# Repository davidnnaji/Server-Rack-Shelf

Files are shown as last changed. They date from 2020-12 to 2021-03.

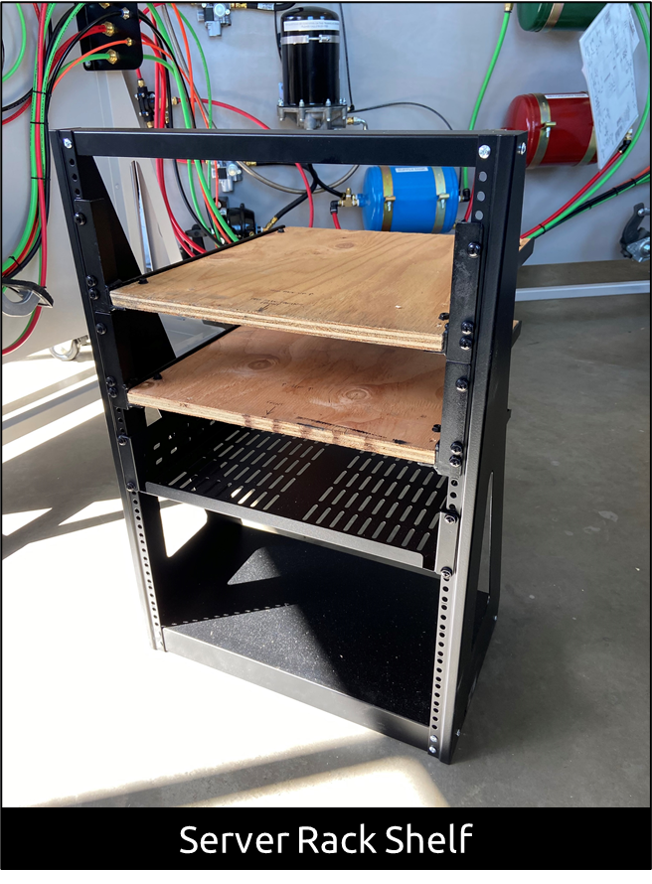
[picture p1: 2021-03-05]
serverrackshelf.png

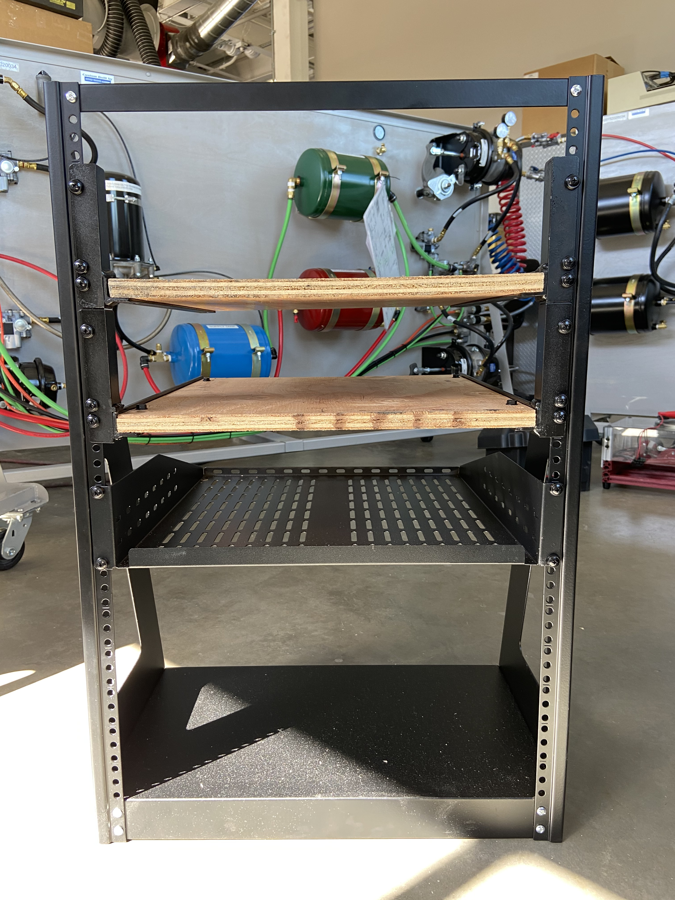
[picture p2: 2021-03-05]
Server Rack Shelf/Photos/IMG_8255.jpg

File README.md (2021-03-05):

# Server Rack Shelf
A wooden shelf for mounting on this [server rack](https://www.startech.com/en-us/server-management/2postrack16). Designed in Solidworks 2020. Project summary included in /docs.

# General Purpose Display Board
A general purpose display board for lab experiments. Ultimately, this did not suit my needs.

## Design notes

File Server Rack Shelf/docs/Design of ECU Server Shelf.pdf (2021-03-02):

# Design of ECU Server Shelf

### David Nnaji

# Problem Definition

## An engineering research group at CSU is developing a remote vehicle network test platform. Continuous operation of electronic control units (ECUs), computers, servers, and other electrical hardware is expected. An organized means of mounting ECU equipment in standard 19-inch racks (server racks) is

desired.

CUMMI
NS ECU

# Needs Analysis

Primary Function:
Support a vehicle ECU and its equipment on standard 19” racks Secondary Function(s):
None
Timeline:
January 1

st – January 30th 2021
Where:
Powerhouse Energy Institute Engine Control Room Who:
SystemsCyber Research Group

# Requirements

System Operational Requirements (SR)
- SR1 – System shall be securable to a standard 16U* 19” two-post server rack.
- SR2 – System height shall not exceed 3U.
- SR3 – System weight shall not exceed 52.5 lb. (15% of rack weight capacity).
- SR4 – At minimum, the system shall support an ECU, 12V power adapter, and an SSS2 unit.

*1U = 1.75 in.
Key Figures of Merit (FOMs):
Material Cost (Mc) – Dollars ($)
Manufacturing Time (Mt) – Hours
Composite Failure Rate (l) – Likelihood a shelf is not made according to design Total Design Cost (TC) – Per Shelf

# Design Alternatives

Alternative 1:
Acrylic-ABS Shelf and Display
Description: A desire for the shelf to doubly function as a project display board was considered but not included in the requirements. Alternative 1 attempts to satisfy this desire and the requirements by using laser cut 1/8” acrylic sheets, velcro, 3D-printed components, and available lab material.
Equipment Used:
Laser Cutter, 3D Printer, Power Drill

Alternative 2:
Wood-Steel Shelf
Description: Alternative 2 attempts to use welded 1/8 in. angle iron, screws, plywood, and available lab materials to satisfy the requirements.
Equipment Used:
Mill, Welding Station, Metal Grinder, Horizontal Band Saw, Wood Saw, Power Drill

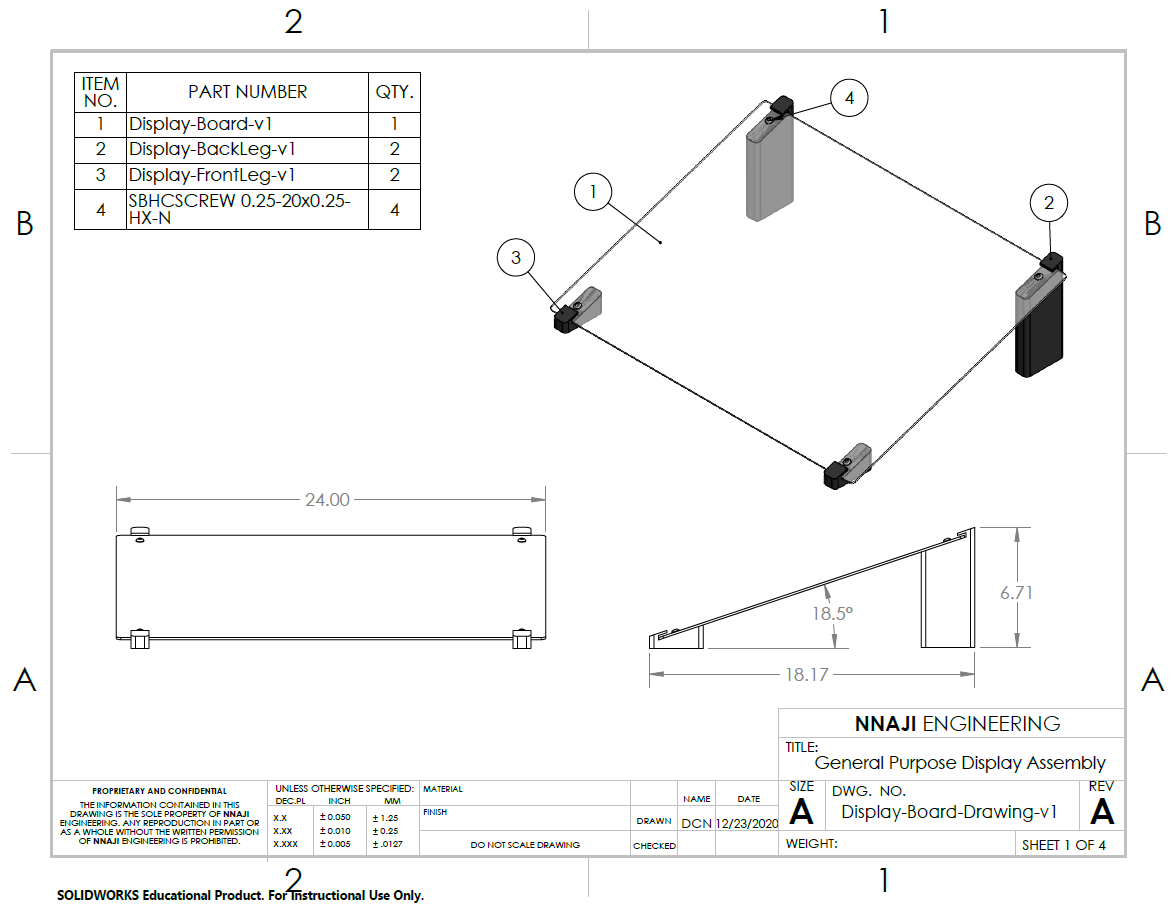
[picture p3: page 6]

# Prototype CAD Drawing Alternative 1

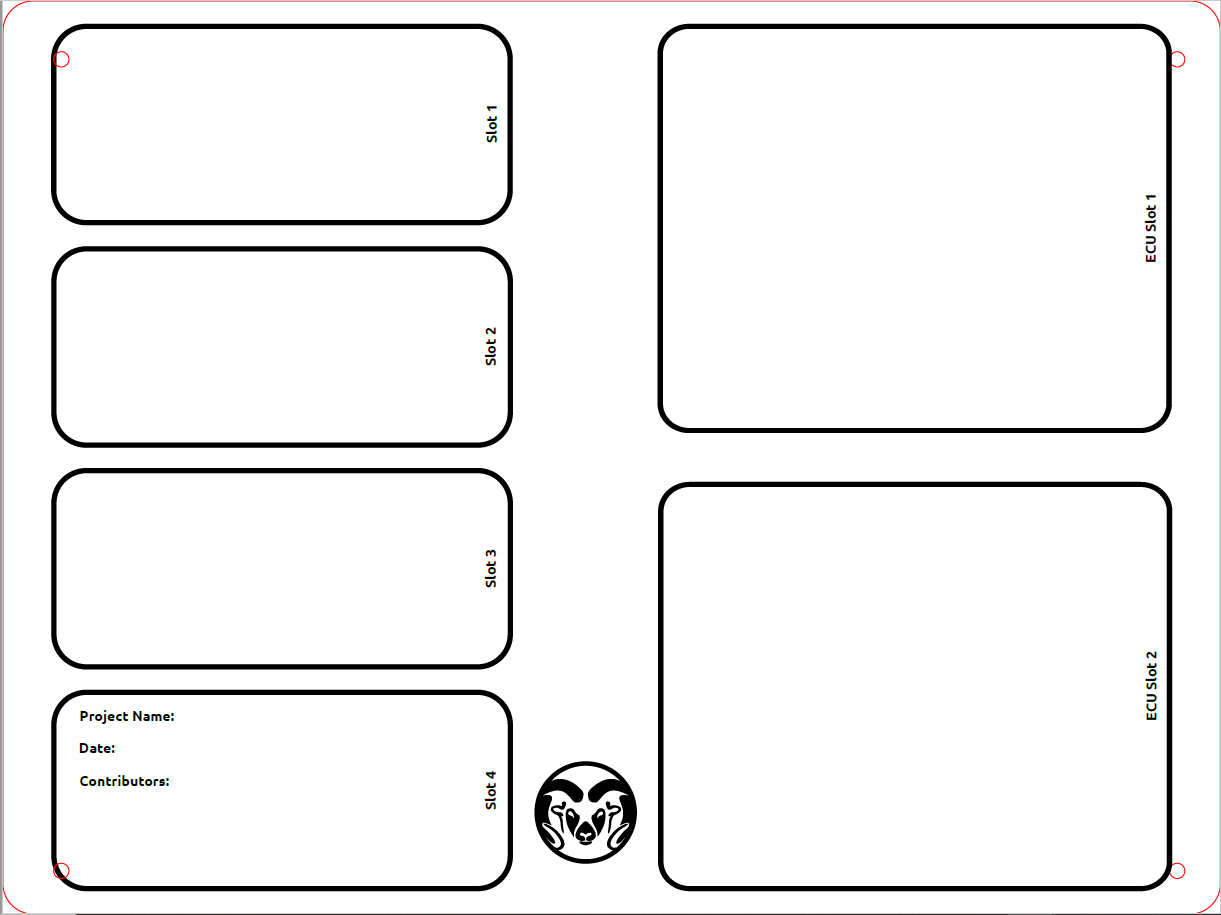
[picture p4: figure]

# Prototype Laser Design Alternative 1

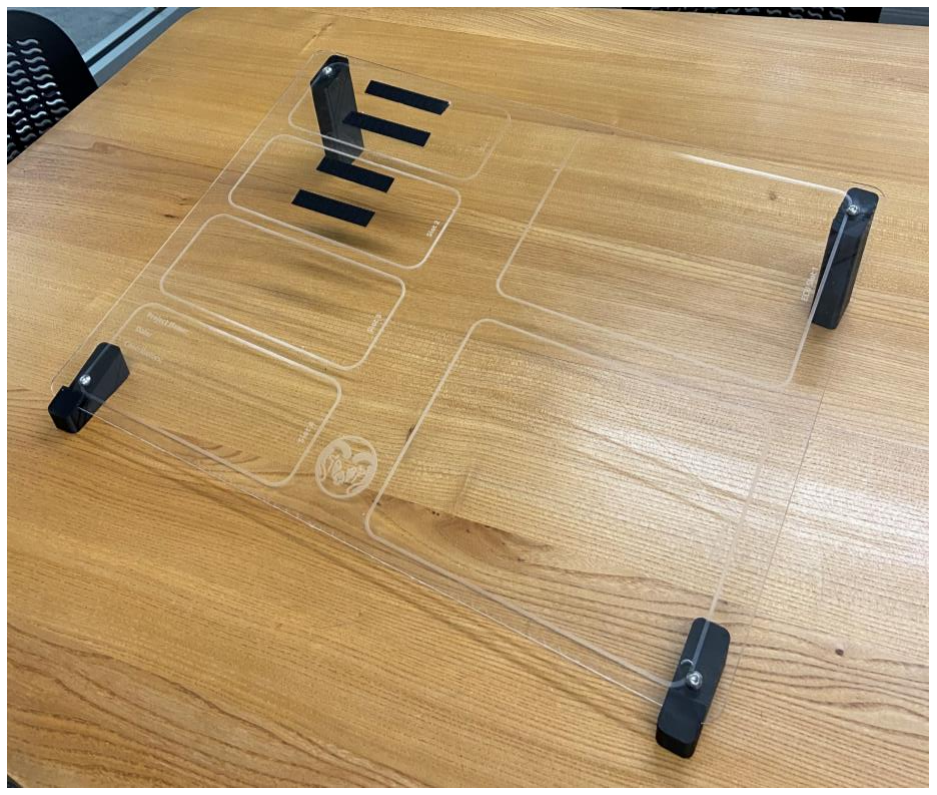
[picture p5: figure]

# Issues: Alternative 1

## - 3D printed components are

difficult reliably produce.

## - 3D printed components require

2-7 hours each to produce.

## - Significant acrylic deflection observed when ECU components

are mounted.

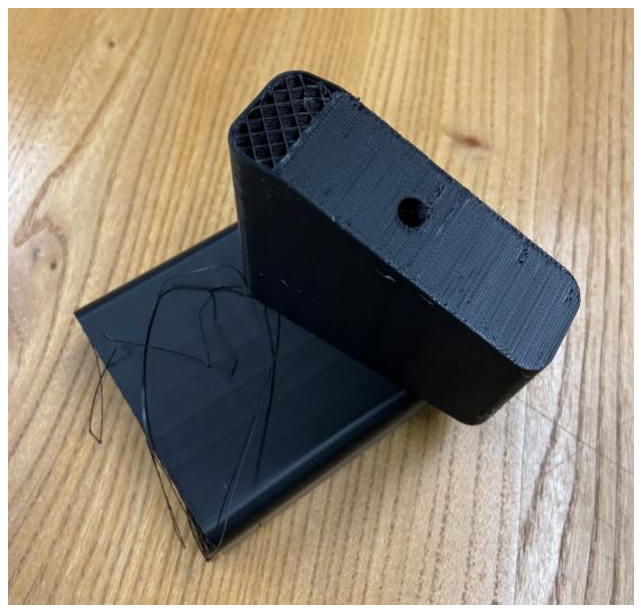
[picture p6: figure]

## - Acrylic to ABS fastening is

relatively weak.

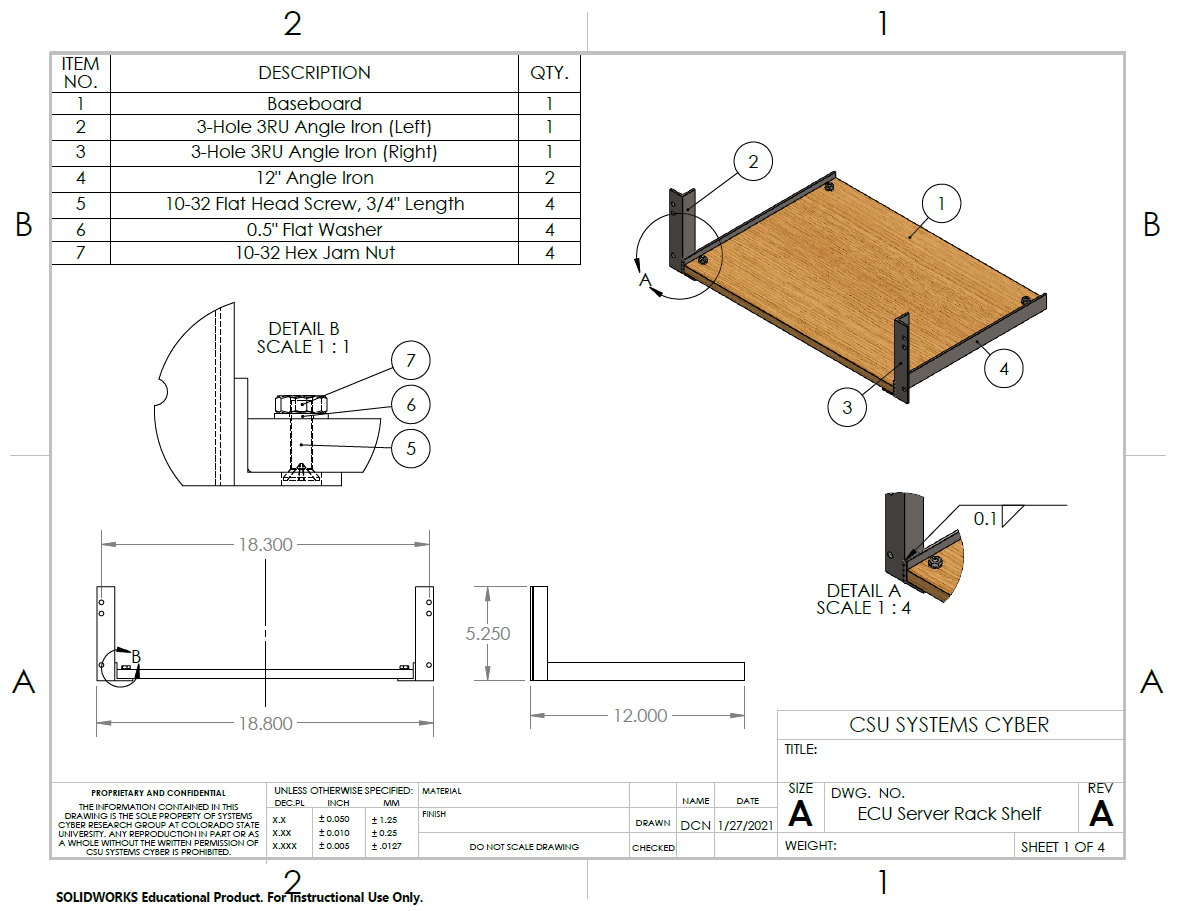
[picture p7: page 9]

# Preliminary CAD Drawing Alternative 2

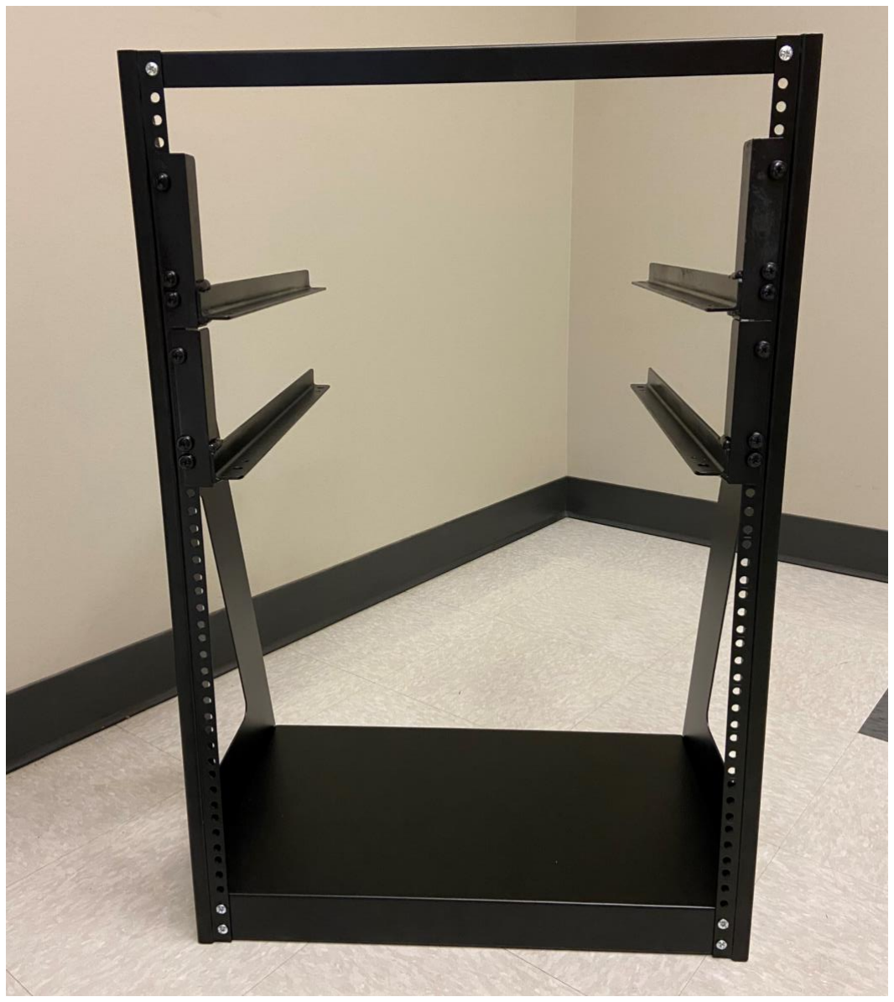
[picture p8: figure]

# Prototype for Wood

## Manufacturing Processes Metal Cutting Metal Grinding Milling Wood Cutting Welding Finishing Painting Assembly

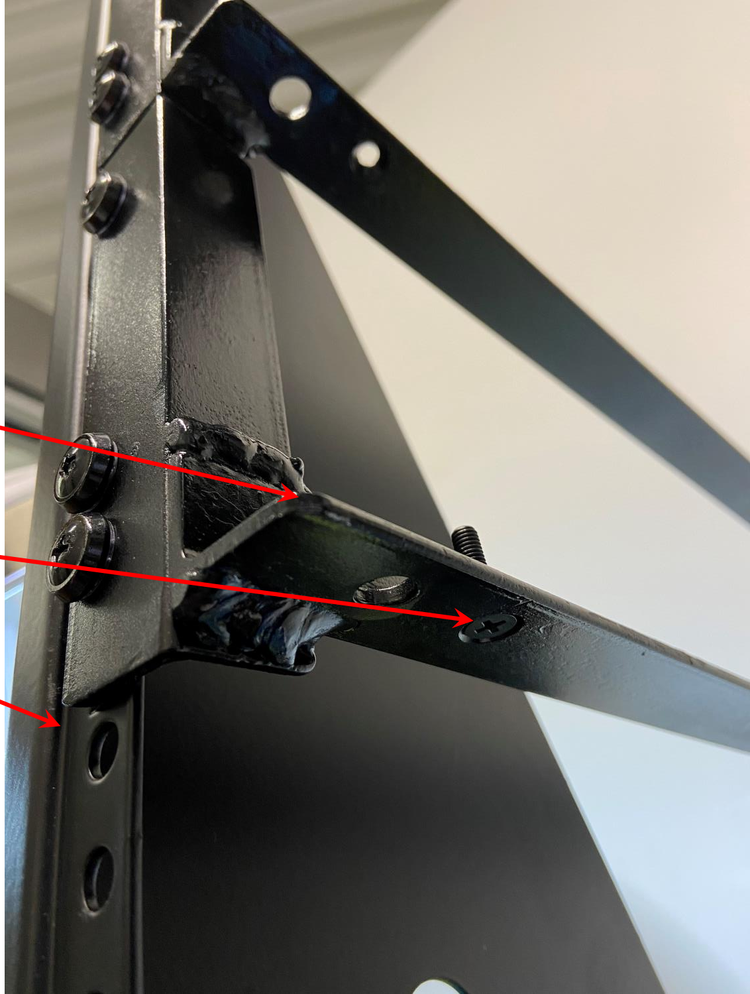
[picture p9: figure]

# Issues: Alternative 2

## - Preliminary Design length was changed from 12” to 18” - Preliminary Design did not include fillet features - Preliminary design did not include countersink for long angle iron

holes.

## - Preliminary Design did not account for server ear shape - Hole spacing and sizes were

adjusted for multiple components.

## - Washer nut replaced with flange

locknut.

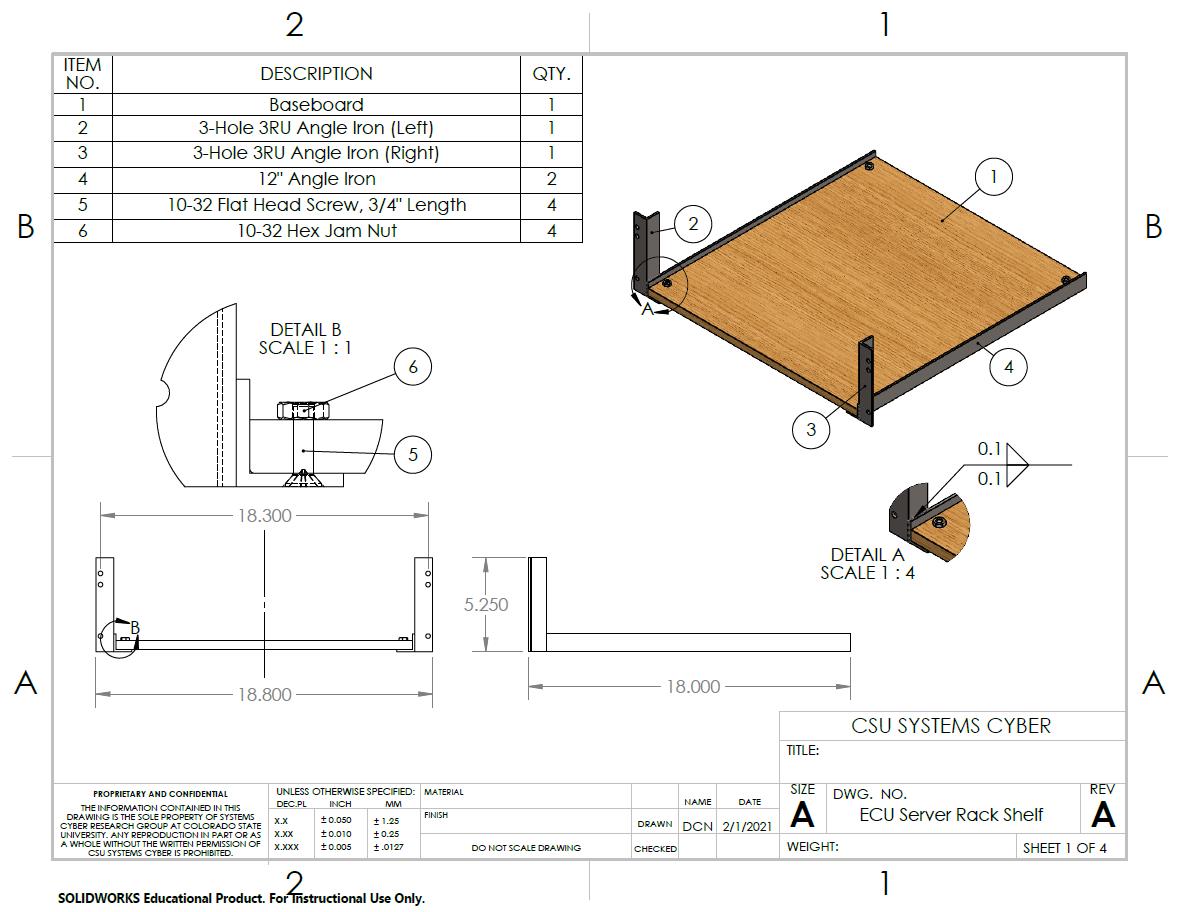
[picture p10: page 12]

# Design-as-Built Drawing Alternative 2

# Trade-Off Study

Alternative 1
Material Cost
19x24 Acrylic, $13.29
136g of PLA, $3.50
#10x0.75 Screw 50 Pack, $9.00 Total: $16.79

Total Design Cost
$16.79 + 9h*ENGC + 17*MC= $542

Manufacturing Time
Laser Cut/Engraving, 0.5h
3D-Prining, 16h
Assembly, 0.5h

Failure Rate
Baseboard, 0.05
Black legs, 0.4
Front legs, 0.2
Composite: 54.4%

Alternative 2
Material Cost
½” 19x18”Plywood, $4.00
Paint, $1
48” 1x1 Angle Iron from 10’, $14.40 #10x0.75 Fasteners 50 pack, $16.16 Total: $35.56

Total Design Cost
$35.56 + 20h*ENGC + 9.1*MC= $772

Manufacturing Time
Metal Cutting, 0.5h
Metal Grinding, 0.3h
Milling, 2h
Wood Cutting, 1h
Welding, 1h
Finishing, 1h

Painting, 3h
Assembly, 0.3h

Failure Rate
Shelf Angle Iron, 0.15
Mount Angle Iron, 0.1
Baseboard, 0.05
Composite: 27.3%

Engineering Cost (ENGC): $30/hr Manufacturing Cost (MC): $15/hr

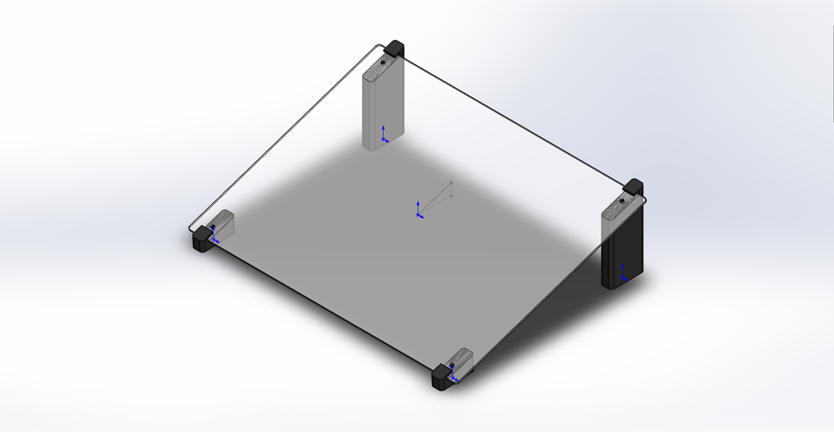
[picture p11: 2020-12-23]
General Purpose Display/Images/screencapture-v1.png

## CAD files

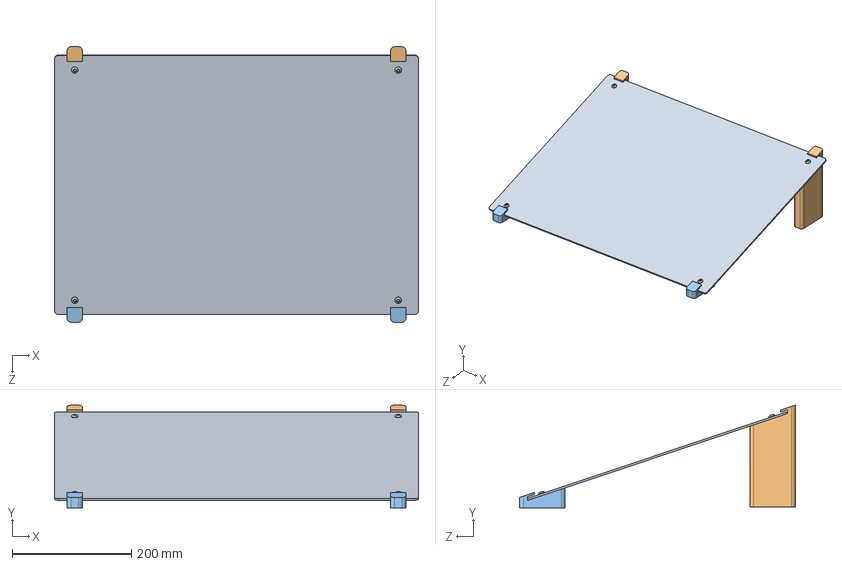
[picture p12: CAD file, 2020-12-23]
General Purpose Display/Assemblies/Display-Board-v1.SLDASM
609.6 x 171.9 x 461.6 mm
Display-Board-v1
Display-BackLeg-v1 x 2
Display-FrontLeg-v1 x 2
socket button head cap screw_ai x 4

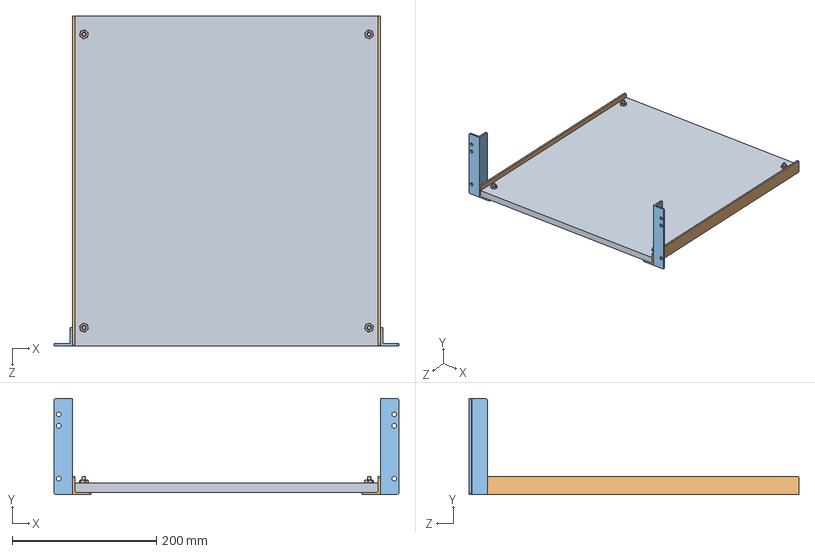
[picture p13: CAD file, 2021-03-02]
Server Rack Shelf/Assemblies/ECU Server Rack Shelf.SLDASM
477.5 x 133.4 x 457.2 mm
Baseboard
Long Angle Iron x 2
3RU Angle Iron x 2
flat head screw_ai x 4
hex jam nut_ai x 4

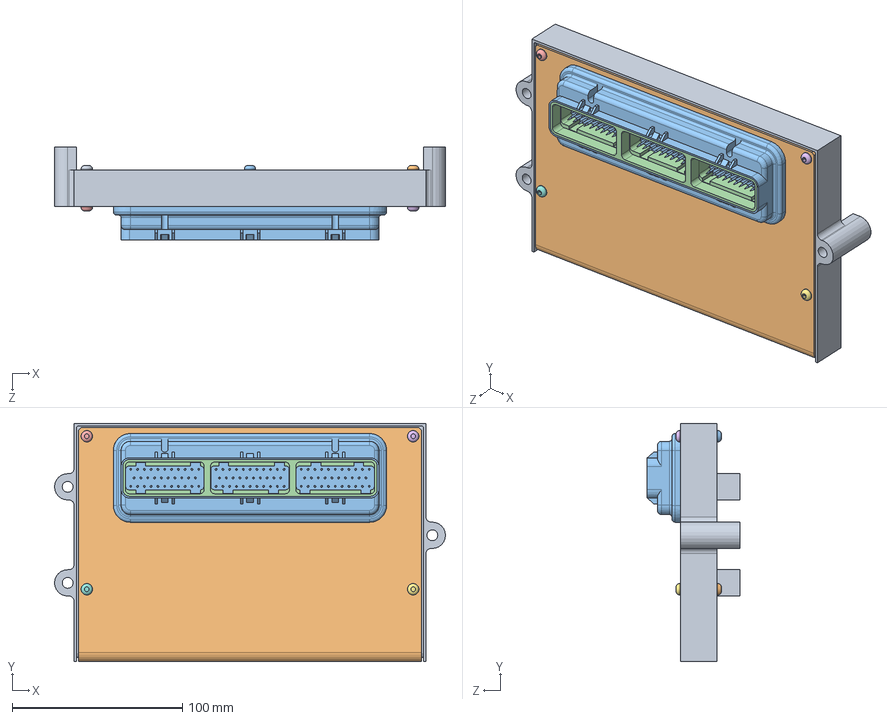
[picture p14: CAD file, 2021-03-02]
Server Rack Shelf/Assemblies/Generic ECU/Grand Cherokee ECU.SLDASM
230.0 x 140.0 x 54.5 mm
Grand Cherokee ECU.sldasm-Part-1
Grand Cherokee ECU.sldasm-Part-2
Grand Cherokee ECU.sldasm-Part-3
Grand Cherokee ECU.sldasm-Part-4
Grand Cherokee ECU.sldasm-Part-5
Grand Cherokee ECU.sldasm-Part-6
Grand Cherokee ECU.sldasm-Part-7
Grand Cherokee ECU.sldasm-Part-8
Grand Cherokee ECU.sldasm-Part-9
Grand Cherokee ECU.sldasm-Part-10
Grand Cherokee ECU.sldasm-Part-11

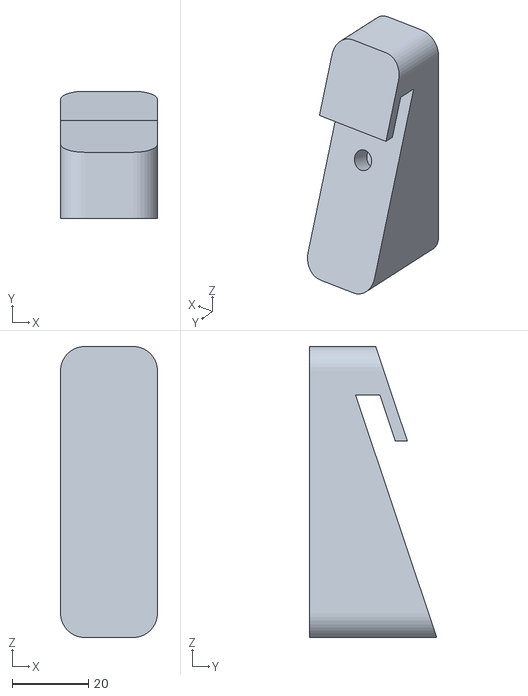
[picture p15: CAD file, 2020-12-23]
General Purpose Display/3D Print Files/Display-FrontLeg-v1.STL
25.4 x 33.4 x 76.2

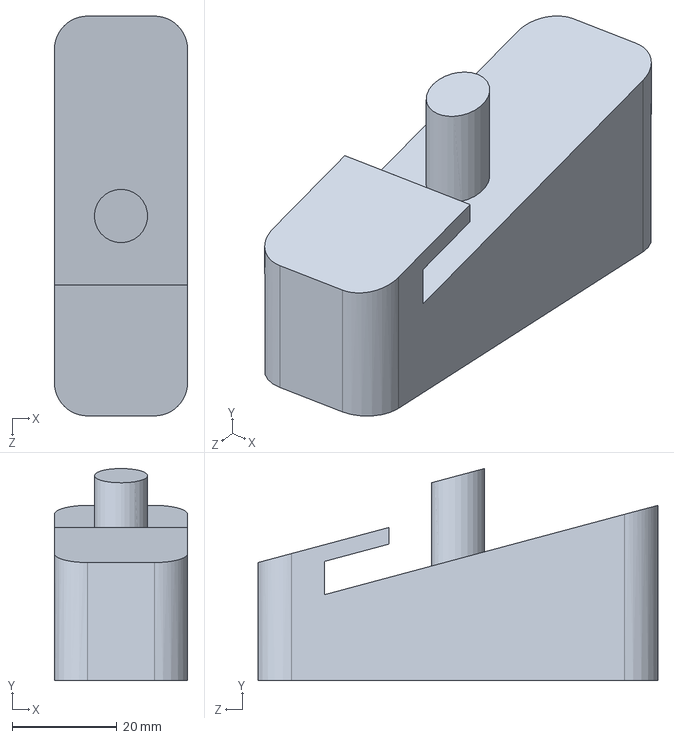
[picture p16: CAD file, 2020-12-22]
General Purpose Display/Parts/v2/DARPADisplay-FrontLeg-v2.SLDPRT
25.4 x 40.4 x 76.2 mm

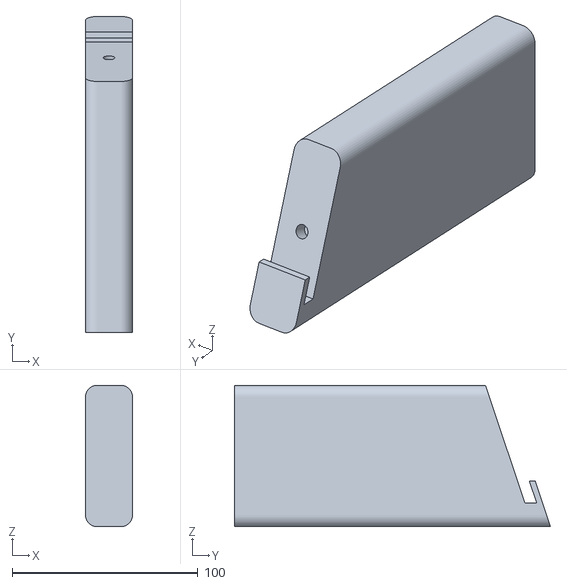
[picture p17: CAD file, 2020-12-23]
General Purpose Display/3D Print Files/Display-BackLeg-v1.STL
25.4 x 170.3 x 76.2

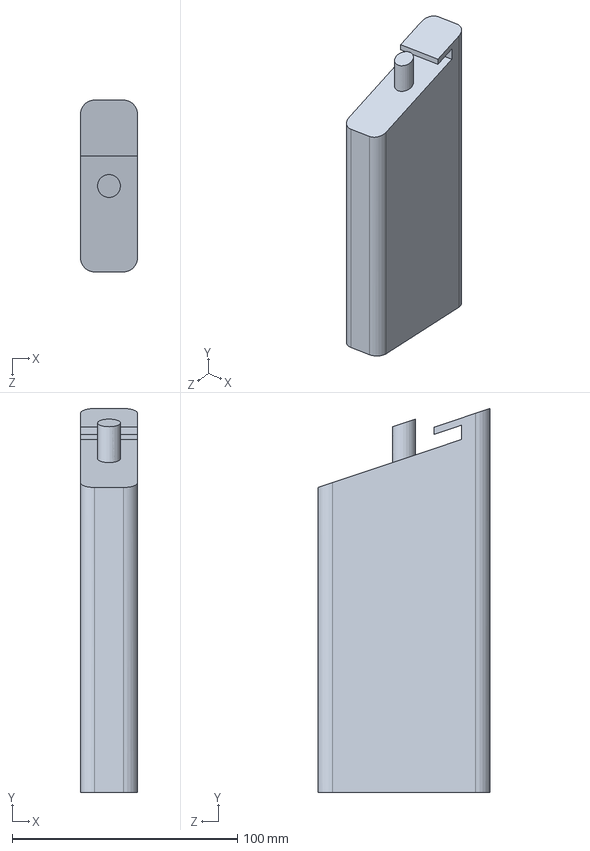
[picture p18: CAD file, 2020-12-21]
General Purpose Display/Parts/v2/DARPADisplay-BackLeg-v2.SLDPRT
25.4 x 170.3 x 76.2 mm

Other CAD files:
Server Rack Shelf/Assemblies/Generic ECU/Grand Cherokee ECU.sldasm-Part-5.SLDPRT
Server Rack Shelf/Assemblies/Generic ECU/Grand Cherokee ECU.sldasm-Part-4.SLDPRT
Server Rack Shelf/Assemblies/Generic ECU/Grand Cherokee ECU.sldasm-Part-2.SLDPRT
Server Rack Shelf/Assemblies/Generic ECU/Grand Cherokee ECU.sldasm-Part-7.SLDPRT
Server Rack Shelf/Assemblies/Generic ECU/Grand Cherokee ECU.sldasm-Part-10.SLDPRT
Server Rack Shelf/Assemblies/Generic ECU/Grand Cherokee ECU.sldasm-Part-11.SLDPRT
Server Rack Shelf/Assemblies/Generic ECU/Grand Cherokee ECU.sldasm-Part-6.SLDPRT
Server Rack Shelf/Assemblies/Generic ECU/Grand Cherokee ECU.sldasm-Part-9.SLDPRT
Server Rack Shelf/Assemblies/Generic ECU/Grand Cherokee ECU.sldasm-Part-3.SLDPRT
Server Rack Shelf/Assemblies/Generic ECU/Grand Cherokee ECU.sldasm-Part-1.SLDPRT
Server Rack Shelf/Assemblies/Generic ECU/Grand Cherokee ECU.sldasm-Part-8.SLDPRT
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

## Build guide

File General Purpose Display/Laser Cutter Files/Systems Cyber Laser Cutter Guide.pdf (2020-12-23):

Written by David Nnaji

EPILOG Helix Laser Cutter Guide Systems Cyber
December 22nd, 2020
Introduction
The Systems Cyber Research Group owns a laser machine capable of cutting and engraving acrylic, wood, plastic, glass, and other materials [1]. It is located in the CSU Powerhouse Energy Campus garage bay and has the following specifications:

Make: Epilog
Model: Helix Mini 24
Model Number: 8000 Laser System Serial Number: 8040 2024 8032 418R CSU Asset Number: 331 289
Date of Manufacture: May 2020 Acquisition Date: May 2020
Engraving Area: 24" x 18" (610 x 457 mm)
Laser Wattage: 30, 40, 50, 60, or 80 watts

This is a quick guide to using the Helix in a manner that is safe for both the operator and the machine. More information, including in-depth training from Epilog [5], can be accessed via the links provided in references section.

Part 1. Connect PC to Helix and Power ON
a) With the Helix turned off, connect USB from PC to the Helix.
b) Power on the Helix using the switch located on the lower left of the device. Wait a few moments for it to boot-up.
c) For Windows devices open Control Panel > View Devices and Printers.
d) If this is your first time connecting your PC to the Helix, the new device should be available under the Unspecified section of Devices and Printers.

Part 2. Installing the Epilog Driver
The laser cutter requires a special driver in addition to the printer drivers already installed on Windows. Skip this part if you have already installed and updated the Epilog Driver.

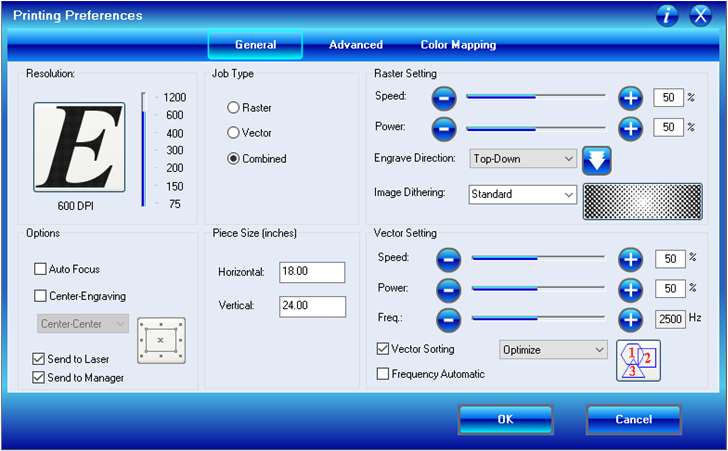
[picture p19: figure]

The Epilog Driver Window

a) Download the driver executable file for the ‘Mini18/24 Helix’ from the Epilog Laser Firmware and Driver Downloads page [2].
b) Run the executable file, copy the path to clipboard for later use, and select ‘Unzip’.

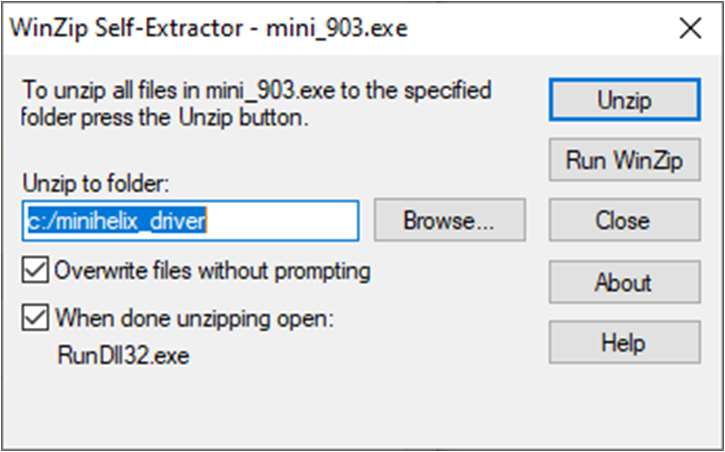
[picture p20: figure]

Executable Window

c) Open Windows Control Panel > View Devices and Printers.
d) In the Unspecified section of Devices and Printers, right click on the laser’s icon, then click Properties.
e) Select the Hardware tab.
f) Select the device EpilogEngraver. Then click Properties.
g) Click Change Settings.
h) Click the Driver tab.
i) Click Update Driver….
j) Click Browse my computer for driver software.
k) Click the Browse key to direct your computer to the driver path OR paste the driver path copied from step b (C:/minihelix_driver).
l) Once the proper path has been entered click Next.
m) Wait while until the progress window disappears, then you may be asked if you want to install this driver. Click Always trust software from “Epilog Corporation” then Install.
n) Your Epilog Laser Print Dashboard has been successfully installed on the USB port. Click Close.
o) Exit out of previous windows until you see your driver in the Devices and Printers page. Exit this window and you are ready to print!

Part 3. Select a Graphics Editor and Create a Design
There are many graphics editors available that are able to produce graphics and patterns that can be cut or printed to the Epilog. Some of the most common are provided in table X. This guide will use Inkscape to demonstrate how create designs that use the Helix’s etching (raster) cutting (vector) capabilities. It which is available for free online [4].

Common Graphics Software

The primary difference between raster and vector graphics is that raster graphics are composed of pixels, while vector graphics are composed of paths or lines. When the Helix is given a vector, it will switch its power settings and follow the path of a line producing a cut in the material. When the Helix is given a raster, it will switch its power settings and etch in a pattern similar to that of a normal ink printer

Open Source
CorelDRAW
Photoshop
Gimp | x
Adobe Illustrator
Inkscape | x
EngraveLab*
*CD-ROM came with Helix and is availble in the lab from left to right. This will produce an etch assuming the power settings aren’t set too high. The following instructions will show how to make a raster line and a vector line in Inkscape.
a) Download Inkscape.
b) Open Inkscape, start a new file and go to File > Document Properties.
c) Under the page tab set the general display units to inches.
d) Change the custom size to 24 x 18 in.
e) Change the Scale x to 1.
f) Adjust the Background, Border, and Display Settings as desired and close the window.

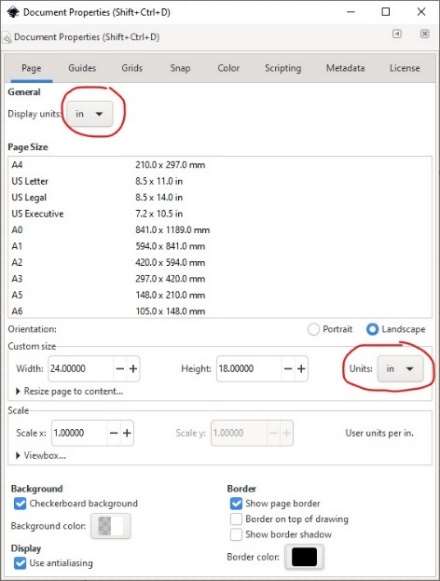
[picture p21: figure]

Inkscape Document Properties Window

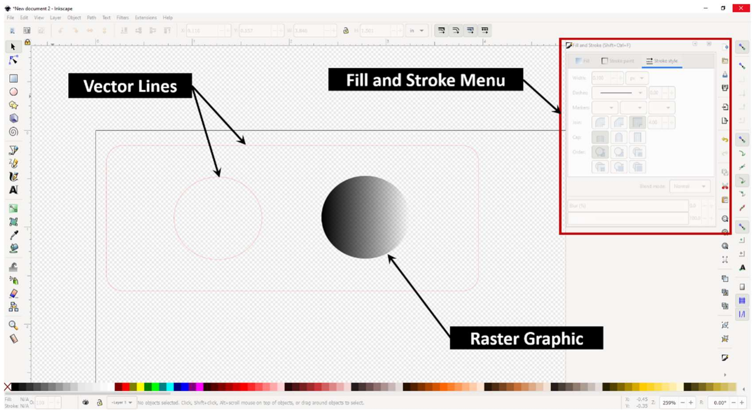
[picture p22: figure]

Vector Lines, Raster Graphic, and Fill and Stroke Menu

g) Select the square tool and create a 1x2 inch rectangle. (If the rectangle is not visible, change the color by selecting the object and clicking any color at the bottom of the window.
h) Adjust the rounded edges with the edit nodes tool .

i) Using the circle tool , create two circles as shown.
j) To turn one circle and the rectangle into vectors, select both objects (hold Shift) and go to Object > Fill and Stroke…
k) Adjust the Fill settings to No paint
l) Adjust Stroke paint color to RGBA “ff0000ff”. (any color is fine but red is very visible)
m) Adjust Stroke style width to 0.1 px. (Any value 0.00 < x < 0.01 will be interpreted as a vector).
n) To turn one circle into a raster, select the other circle, and go to Object > Fill and Stroke…
o) Adjust the Fill settings as desired. Do not select No paint.
p) Adjust Stroke paint color as desired or none.
q) Adjust Stroke style width to any value > 0.1px or to 0px.
r) Save the graphic as a PDF. Accept any default settings.

Part 4. Prepare Laser Cutter
a) Open the laser hood and ensure the bed is free of debris.
b) Lower air duct using switches located near the left of the Helix and fasten it to the blower output.

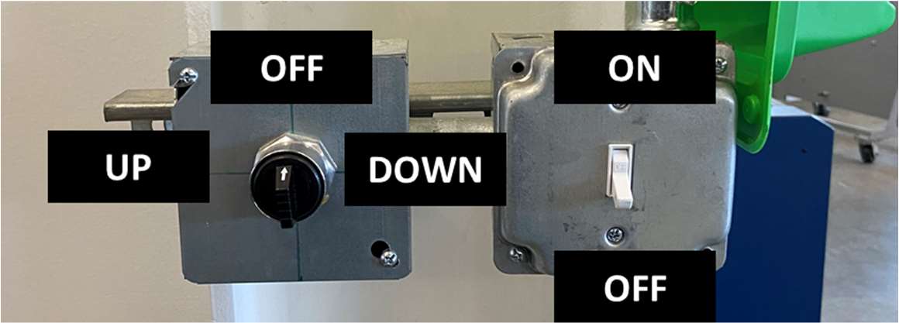
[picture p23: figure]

Air Duct Control Switches

c) Turn on the facility air duct and the blower.

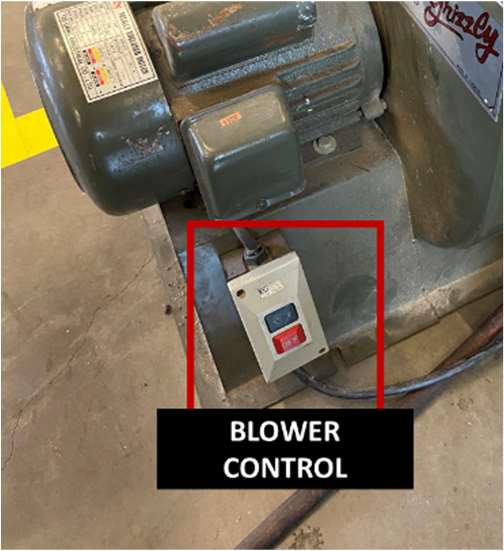
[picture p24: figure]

Blower ON/OFF Switch

d) Connect to PC to Helix via USB.
e) Turn on the laser cutter.
Step 5. Send Design to Printer and Cut
a) Open your design in Adobe Acrobat Reader* (highly recommended)
b) Open the Epilog Driver Window, File > Print > Properties
c) To select the appropriate settings for your print, consider the following:

I. Is the graphic made of only vectors? Select Vector job type.
II. | Is the graphic made of only raster illustrations? Select Raster job type.
III. | A combination of both? Select Combined job type.
d) Select Auto-Focus on.
e) (Optional) Set Piece Size to 24 x 18 in to use the entire bed.
f) Adjust Vector Settings (Speed, Power, Frequency) depending on the material**.
g) Click OK.
h) In the Adobe Print Settings change Orientation to Auto.

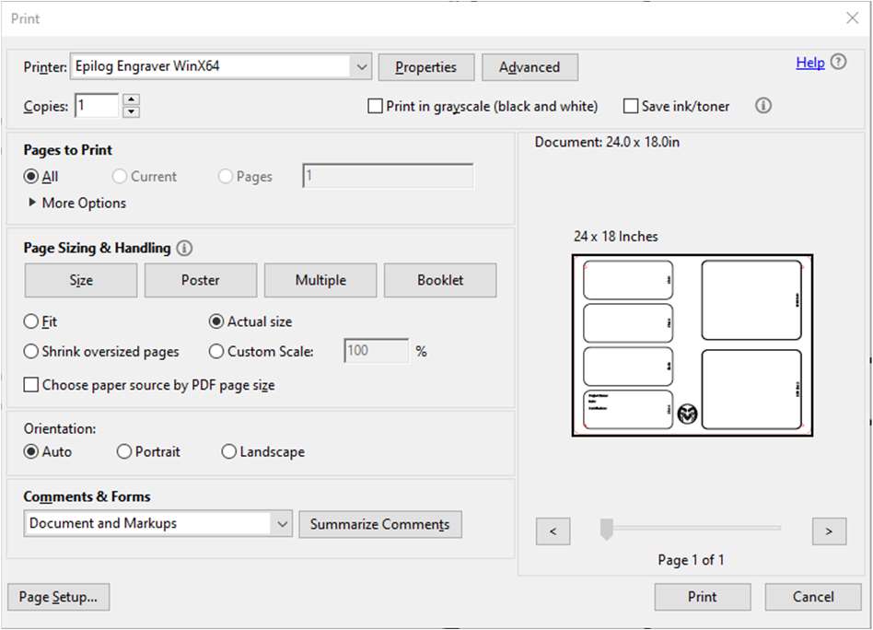
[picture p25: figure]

Adobe Acrobat Print Settings

i) Select Actual size.
j) Deselect “Choose paper source by PDF page size.” Dimensions should match those of the PDF file.
k) Click Print to send the job to the printer.
l) Find the sent the job and press Start button.

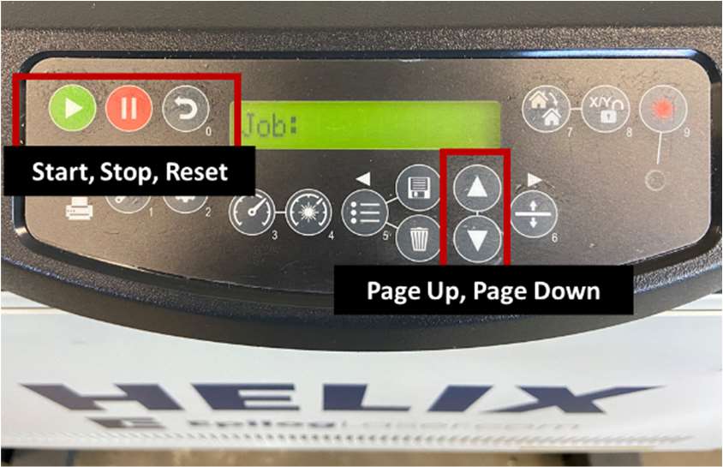
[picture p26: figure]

Important Buttons on the Helix

m) Inspect the job as it starts. Stop, adjust, and reset as needed.
n) Allow the smoke from the cut to be evacuated well after the job has been completed.

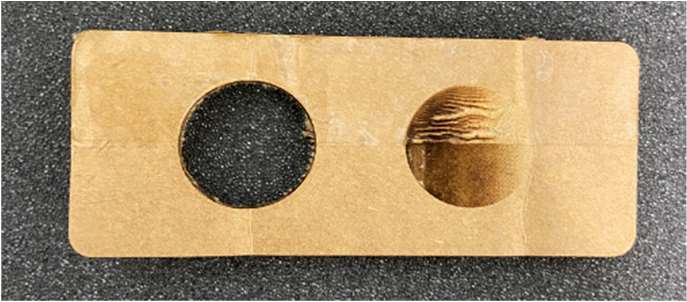
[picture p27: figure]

Example Design Applied to Scrap Piece of Cardboard

*Adobe Acrobat Reader seems to be the only program that generates the right output to the Helix when given a PDF
**Material settings can be found through [5] or through trial and error. In the future a table can be made for use by the Systems Cyber group.
Step 6: Shutdown and Cleanup
a) When all smoke has been cleared and all jobs have been completed, turn off the air duct and the blower.
b) Disconnect air duct and raise it.
c) Turn off the Helix.
d) Clear the table of debris.
e) Clear debris from under the table. Accessible by lowering front panel.

References
[1] Mini Helix Promotional Webpage, epiloglaser.com/laser-machines/mini-helix-engraver-cutter/
[2] Epilog Driver Webpage, epiloglaser.com/tech-support/epilog-drivers.html
[3] Mini Helix Driver installation Guide, epiloglaser.com/assets/downloads/driver-instructions/minihelix-driver-install.pdf
[4] Inkscape Website, inkscape.org
[5] Epilog In-Depth Training (must request access), www.training.epiloglaser.com/login.php

Recommended Vector SPF Settings for Materials:
Coming Soon!

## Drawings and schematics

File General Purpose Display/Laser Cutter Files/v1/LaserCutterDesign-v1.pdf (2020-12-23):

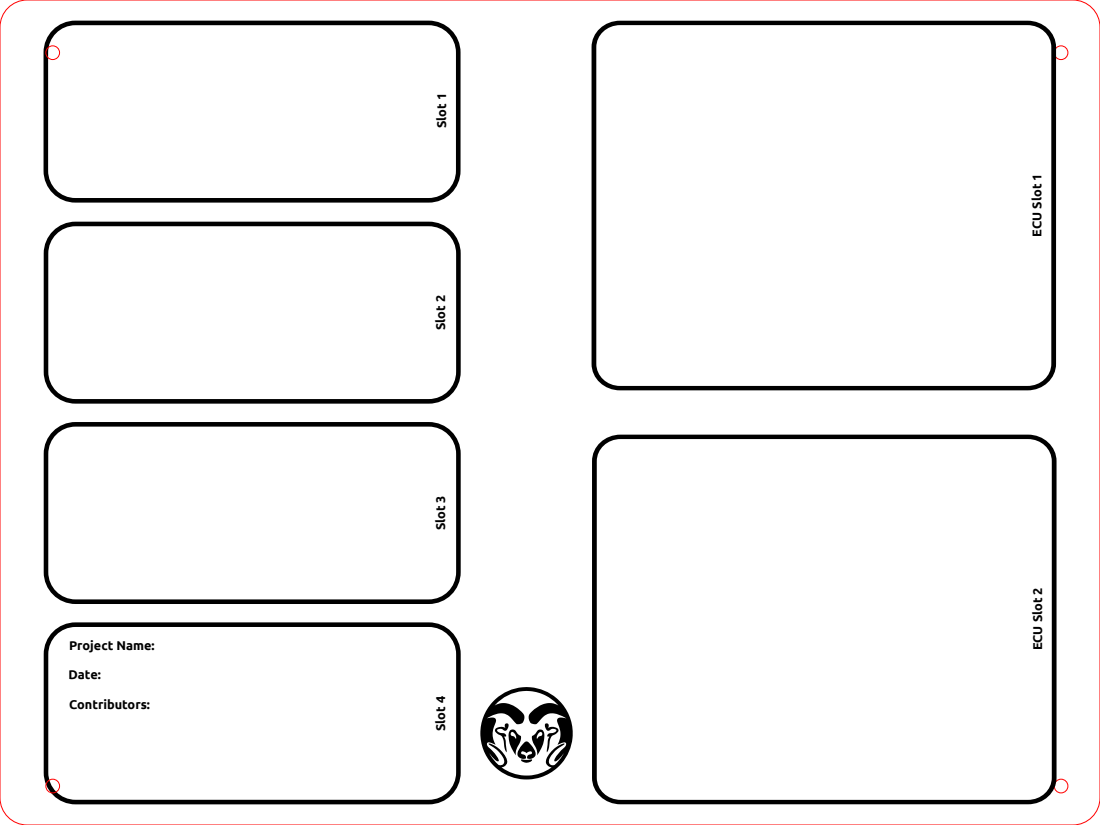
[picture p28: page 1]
Project Name:; Date:; Contributors:; Slot 4

Slot 1 Slot 2 Slot 3

ECU Slot 1 ECU Slot 2

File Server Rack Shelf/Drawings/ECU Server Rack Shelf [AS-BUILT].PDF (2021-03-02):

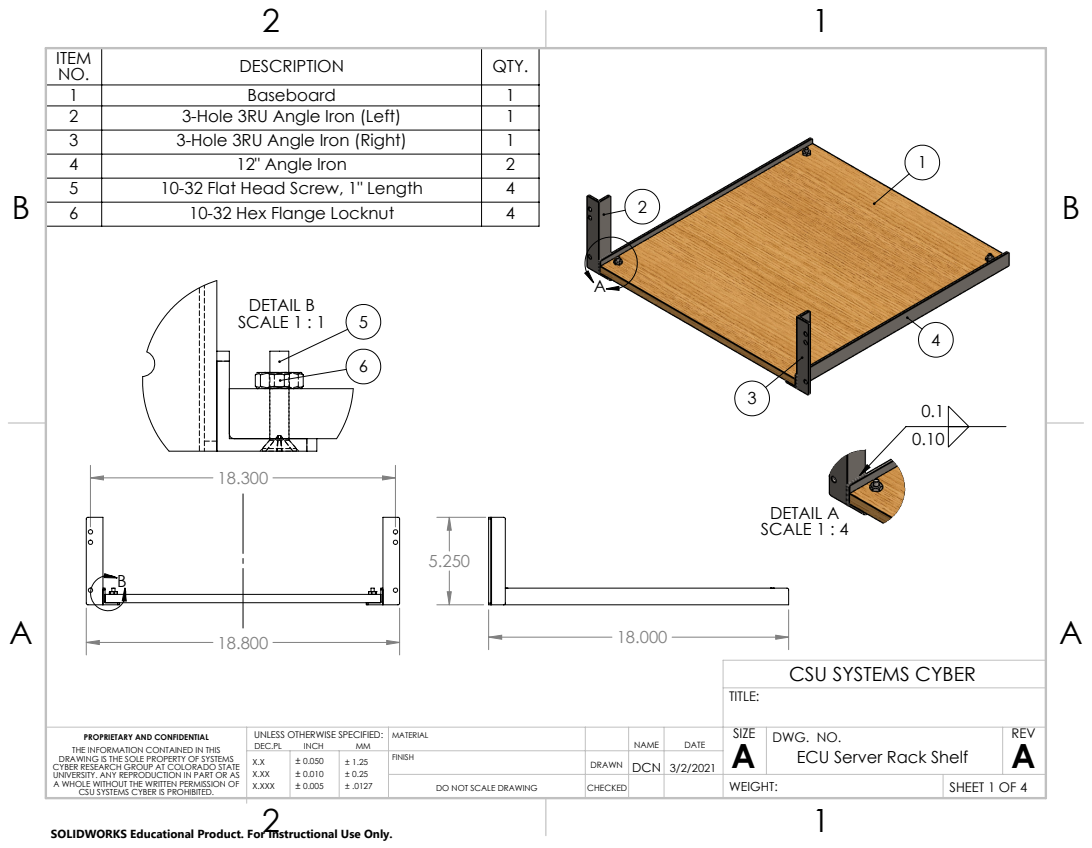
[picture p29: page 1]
DETAIL A SCALE 1 : 4; DETAIL B SCALE 1 : 1

ITEM NO. | DESCRIPTION | QTY.
1 | Baseboard | 1
2 | 3-Hole 3RU Angle Iron (Left) | 1
3 | 3-Hole 3RU Angle Iron (Right) | 1
4 | 12" Angle Iron | 2
5 | 10-32 Flat Head Screw, 1" Length | 4
6 | 10-32 Hex Flange Locknut | 4

CSU SYSTEMS CYBER

PROPRIETARY AND CONFIDENTIAL THE INFORMATION CONTAINED IN THIS DRAWING IS THE SOLE PROPERTY OF SYSTEMS CYBER RESEARCH GROUP AT COLORADO STATE UNIVERSITY. ANY REPRODUCTION IN PART OR AS A WHOLE WITHOUT THE WRITTEN PERMISSION OF CSU SYSTEMS CYBER IS PROHIBITED. | UNLESS OTHERWISE SPECIFIED: DEC.PL INCH MM | MATERIAL | NAME | DATE | SIZE A | DWG. NO. ECU Server Rack Shelf | REV A

X.X X.XX X.XXX | ± 0.050 ± 0.010 | ± 1.25 ± 0.25 | DRAWN FINISH | DCN | 3/2/2021

DO NOT SCALE DRAWING | CHECKED | | WEIGHT: | SHEET 1 OF 4

SOLIDWORKS Educational Product. For Instructional Use Only.

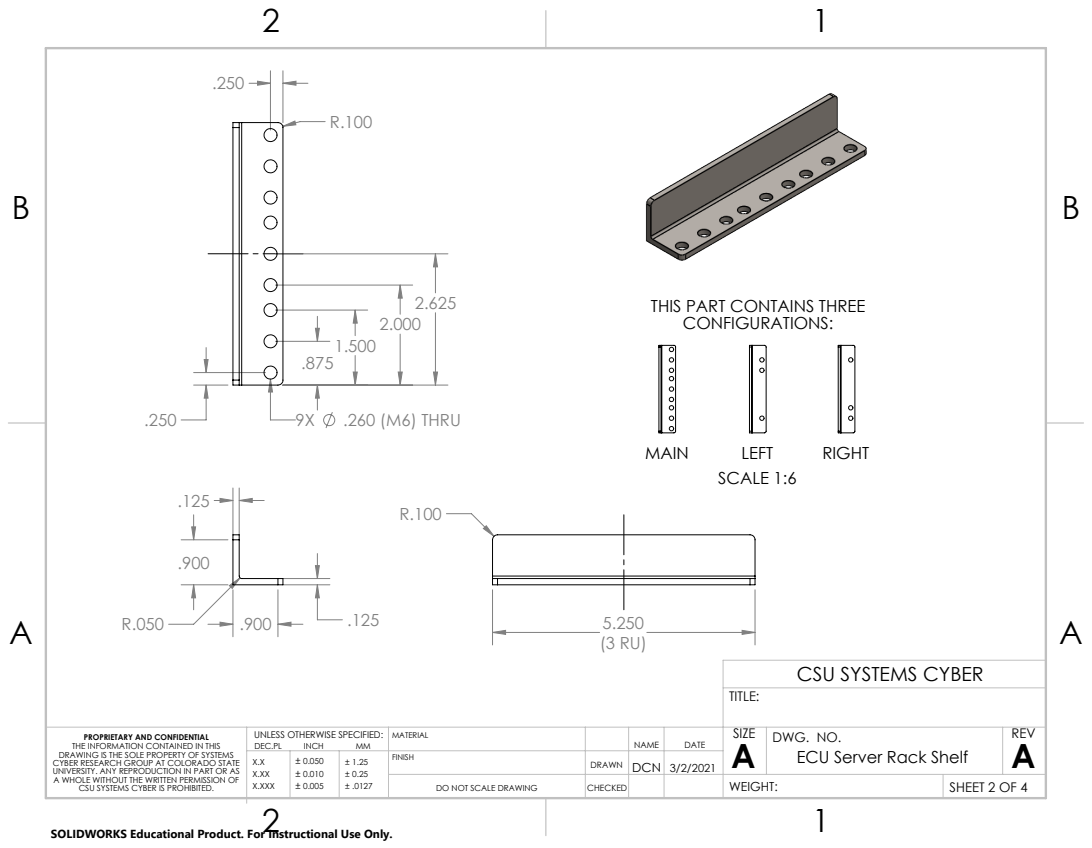
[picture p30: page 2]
.260 (M6) THRU; SCALE 1:6

THIS PART CONTAINS THREE
CONFIGURATIONS:

CSU SYSTEMS CYBER

PROPRIETARY AND CONFIDENTIAL THE INFORMATION CONTAINED IN THIS DRAWING IS THE SOLE PROPERTY OF SYSTEMS CYBER RESEARCH GROUP AT COLORADO STATE UNIVERSITY. ANY REPRODUCTION IN PART OR AS | UNLESS OTHERWISE SPECIFIED: DEC.PL INCH MM | MATERIAL | DCN NAME | 3/2/2021 DATE | SIZE A | DWG. NO. ECU Server Rack Shelf | REV A

X.X X.XX | ± 0.050 ± 0.010 | ± 1.25 ± 0.25 | DRAWN FINISH

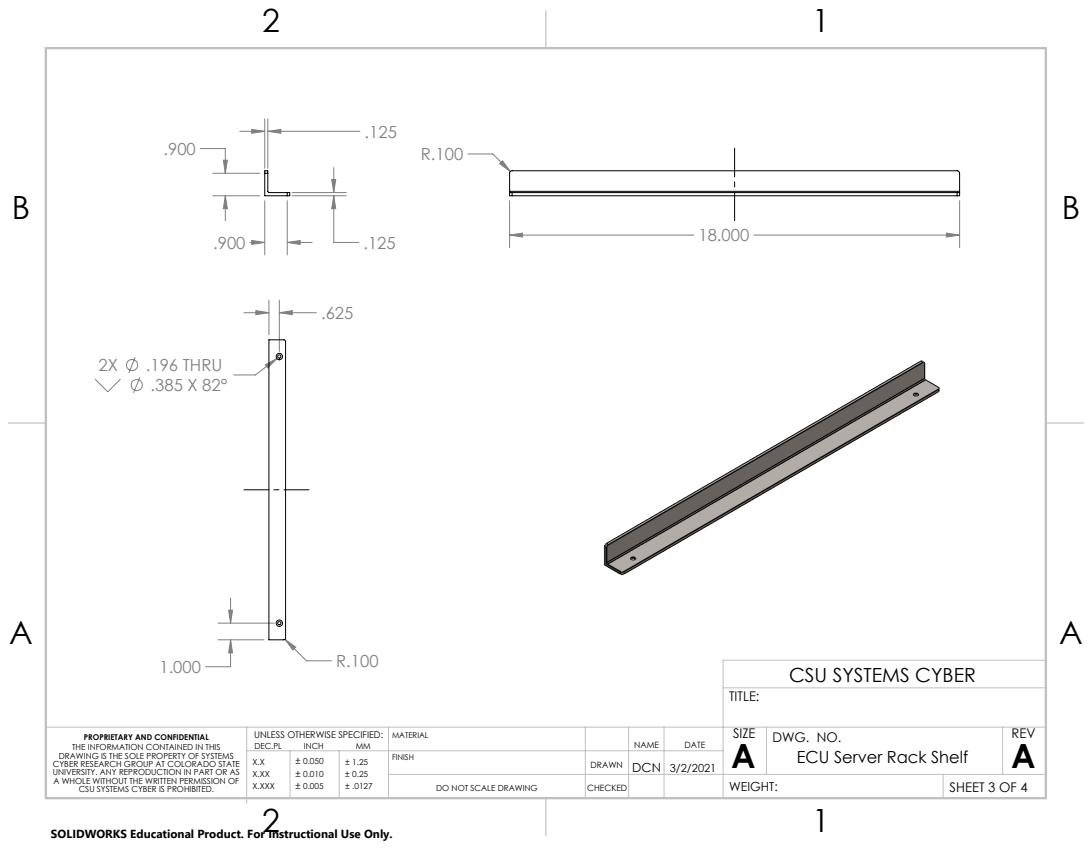
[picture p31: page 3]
.196 THRU

CSU SYSTEMS CYBER

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

X.X X.XX | ± 0.050 ± 0.010 | ± 1.25 ± 0.25 | DRAWN FINISH

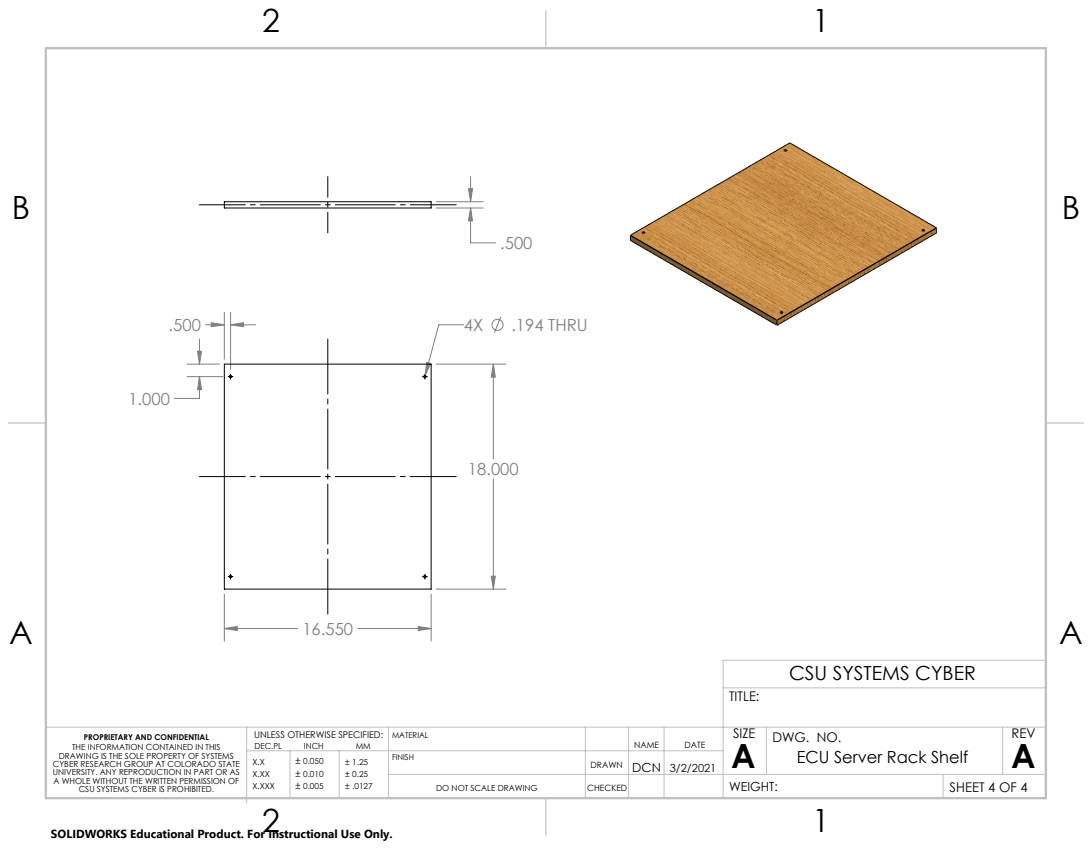
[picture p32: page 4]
.194 THRU

CSU SYSTEMS CYBER

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

X.X X.XX | ± 0.050 ± 0.010 | ± 1.25 ± 0.25 | DRAWN FINISH

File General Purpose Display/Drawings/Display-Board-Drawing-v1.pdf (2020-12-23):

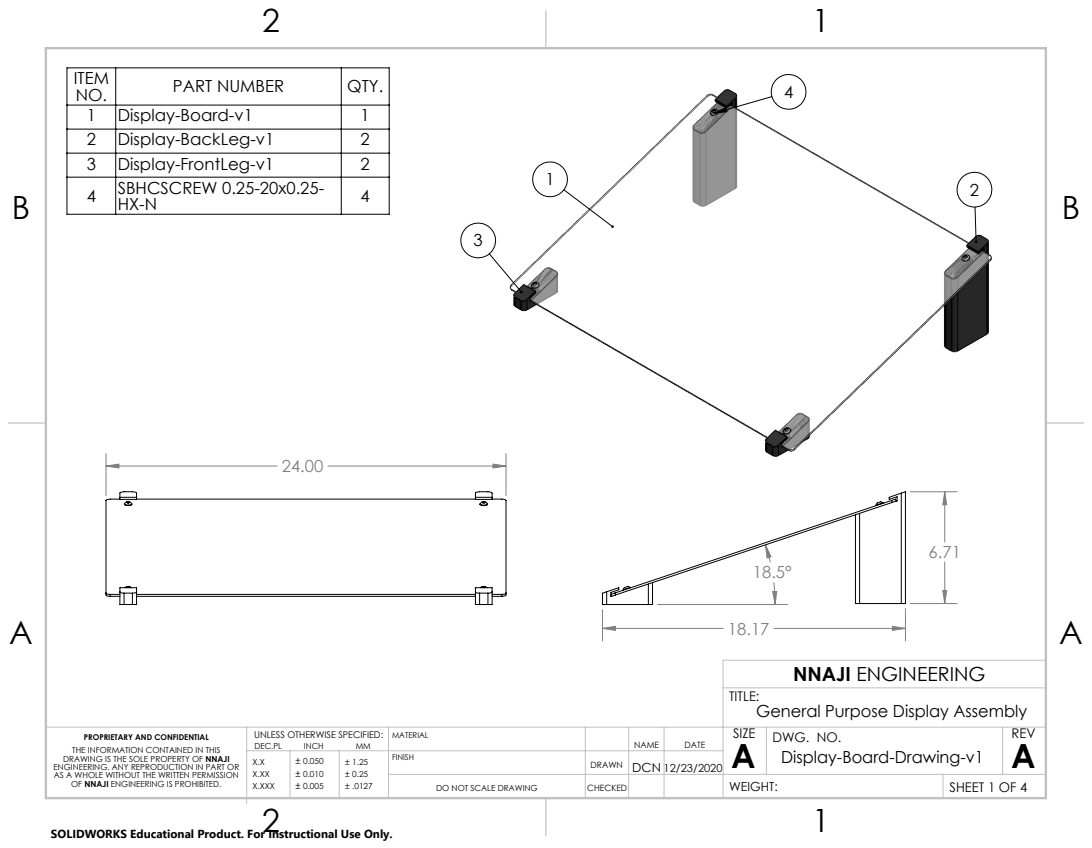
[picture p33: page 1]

ITEM NO. | PART NUMBER | QTY.
1 | Display-Board-v1 | 1
2 | Display-BackLeg-v1 | 2
3 | Display-FrontLeg-v1 | 2
4 | SBHCSCREW 0.25-20x0.25-HX-N | 4

NNAJI ENGINEERING
General Purpose Display Assembly

PROPRIETARY AND CONFIDENTIAL THE INFORMATION CONTAINED IN THIS DRAWING IS THE SOLE PROPERTY OF NNAJI ENGINEERING. ANY REPRODUCTION IN PART OR AS A WHOLE WITHOUT THE WRITTEN PERMISSION OF NNAJI ENGINEERING IS PROHIBITED. | UNLESS OTHERWISE SPECIFIED: DEC.PL INCH MM | MATERIAL | NAME | DATE | SIZE A | DWG. NO. Display-Board-Drawing-v1 | REV A

X.X X.XX X.XXX | ± 0.050 ± 0.010 | ± 1.25 ± 0.25 | DRAWN FINISH | DCN 12/23/2020

DO NOT SCALE DRAWING | CHECKED | | WEIGHT: | SHEET 1 OF 4

SOLIDWORKS Educational Product. For Instructional Use Only.

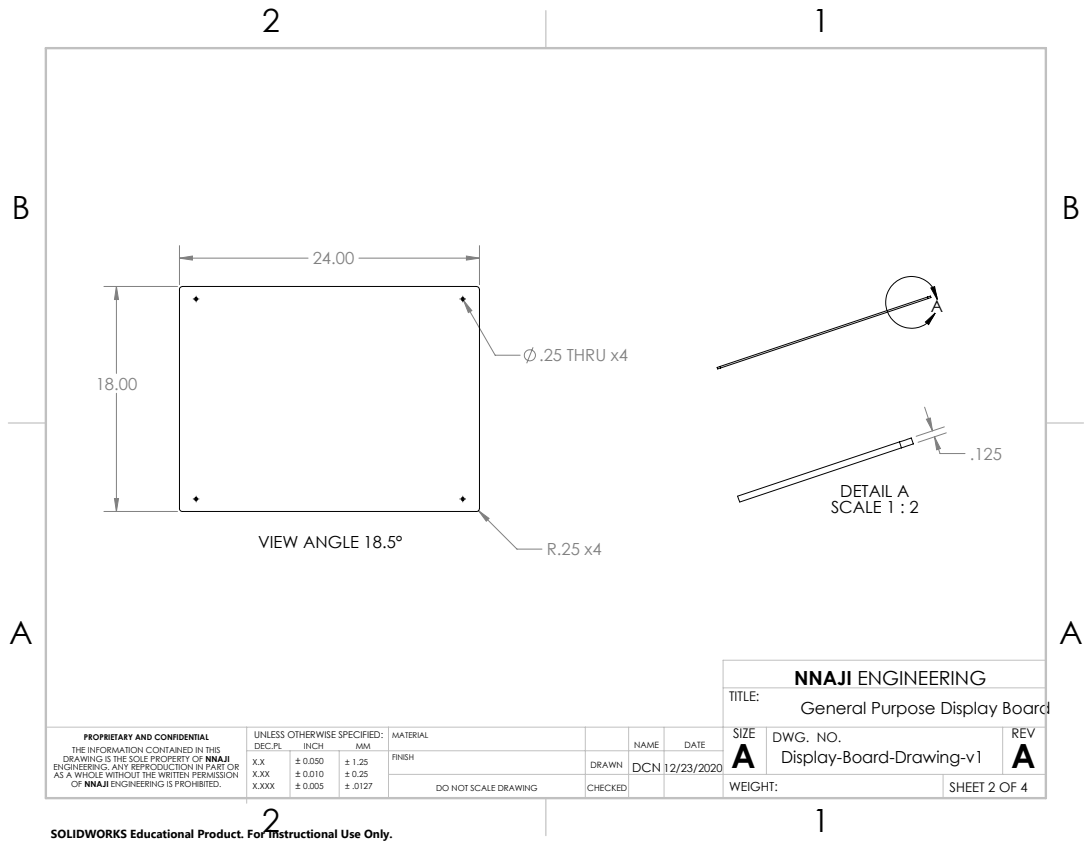
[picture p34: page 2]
DETAIL A SCALE 1 : 2; .25 THRU x4; VIEW ANGLE 18.5°

NNAJI ENGINEERING
General Purpose Display Board

PROPRIETARY AND CONFIDENTIAL THE INFORMATION CONTAINED IN THIS DRAWING IS THE SOLE PROPERTY OF NNAJI ENGINEERING. ANY REPRODUCTION IN PART OR AS A WHOLE WITHOUT THE WRITTEN PERMISSION | UNLESS OTHERWISE SPECIFIED: DEC.PL INCH MM | MATERIAL | NAME | DATE | SIZE A | DWG. NO. Display-Board-Drawing-v1 | REV A

X.X X.XX | ± 0.050 ± 0.010 | ± 1.25 ± 0.25 | DRAWN FINISH | DCN 12/23/2020

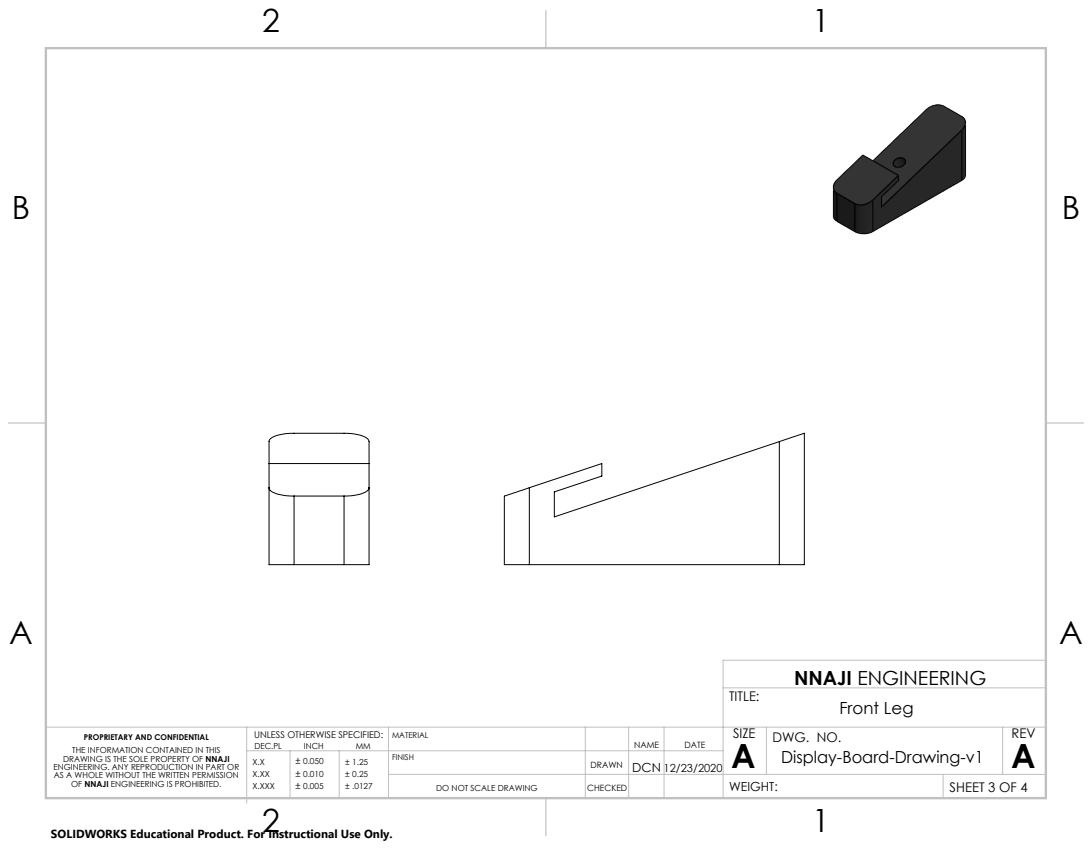
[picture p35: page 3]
Front Leg; NNAJI ENGINEERING

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

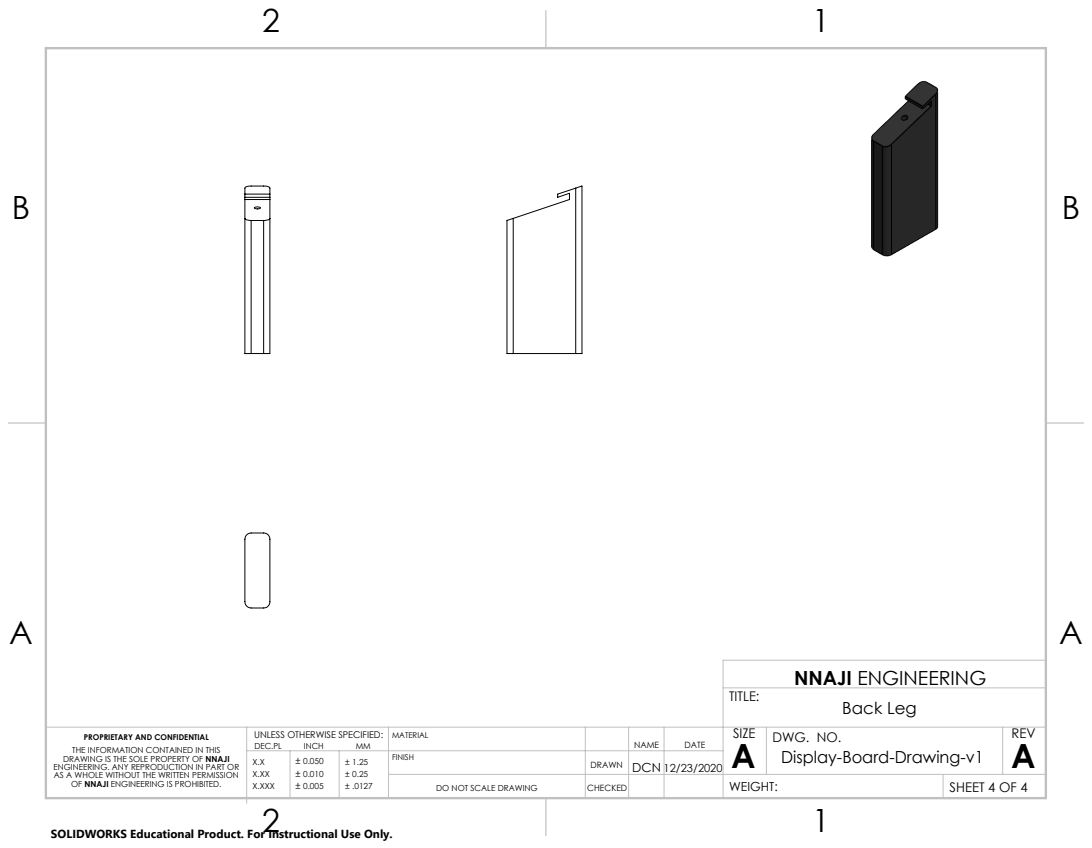
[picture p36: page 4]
Back Leg; NNAJI ENGINEERING

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

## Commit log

2020-12-21 Initial Commit with Part, Assembly, and 3D Print Files
    [DARPADisplay-BackLeg.SLDPRT, DARPADisplay-BackLeg2.SLDPRT, DARPADisplay-Board.SLDPRT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]
2020-12-22 Ssparated versions.
    [DARPADisplay-BackLeg-v1.SLDPRT, DARPADisplay-BackLeg-v2.SLDPRT, DARPADisplay-Board-v1.SLDPRT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]
2020-12-23 Version 1 Files Completed!
    [DARPADisplay-BackLeg-v1.SLDPRT, DARPADisplay-BackLeg-v2.SLDPRT, DARPADisplay-Board-v1.SLDPRT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]
2020-12-23 Drawing PDF Generated
    [Display-Board-Drawing-v1.SLDDRW]
2021-03-02 Minor Revision to Laser File
2021-03-02 Server Shelf Files added
    [#10 Flat Washer.SLDPRT, #10 Hex Jam Nut.SLDPRT, #10-32 Socket Head Cap Screw, 0.75 in. Length.SLDPRT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]
2021-03-05 Updates to presentation, schematic, and README.md
